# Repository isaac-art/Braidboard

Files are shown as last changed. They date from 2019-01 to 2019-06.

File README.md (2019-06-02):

## Braidboard
#### current version: 0119b

<hr>

This began as a sort of hardware version of [BriadLab](https://github.com/isaac-art/BraidLab) but is becoming some kind of distributed-cellular-pattern-generator.

<hr>

### Activity

- [02/06/19] Long break, but been thinking though making a simulator to get a better idea of how this all works. I need more memory in the boards, swapping between frame buffers doesnt allow enough room.
I'm going to sketchout some plans as to what the simulator will look like, but i think i will call it:

```
   ______      ___           __   ____                    __
  / __(_)_ _  / _ )_______ _(_)__/ / /  ___  ___ ________/ /
 _\ \/ /  ' \/ _  / __/ _ `/ / _  / _ \/ _ \/ _ `/ __/ _  / 
/___/_/_/_/_/____/_/  \_,_/_/\_,_/_.__/\___/\_,_/_/  \_,_/  

```

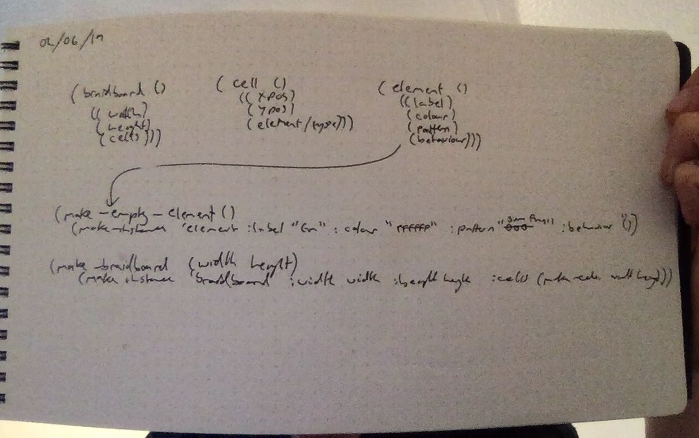
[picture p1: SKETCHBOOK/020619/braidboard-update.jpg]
classes


- [08/02/19] plan for the next week is to work on a font for drawing with. a set of tiles that can connect into different patterns.

- [08/02/19] playing around with images, thinking of having little pattern swatches for the screens, will need to make some bitmaps/font. they can then infect each other flipping bits of the weaves in each other? 

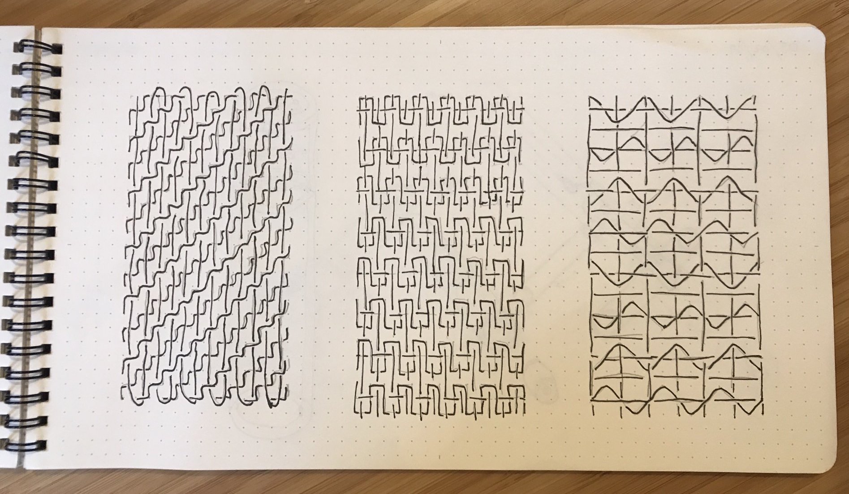
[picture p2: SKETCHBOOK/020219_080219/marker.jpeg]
drawings


<hr>

- [01/02/19] simple version running, 4 possible states, inherit from parents and pass to child. Next try drawing the knot crossings instead of numbers.

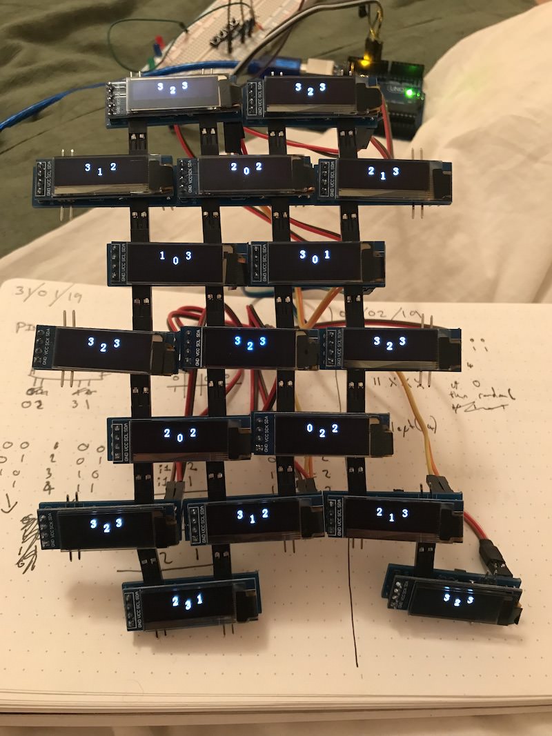
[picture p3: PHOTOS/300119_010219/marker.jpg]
first tests


<hr>

- [29/01/19] Aim to get some coding done this weekend 02/02/19.

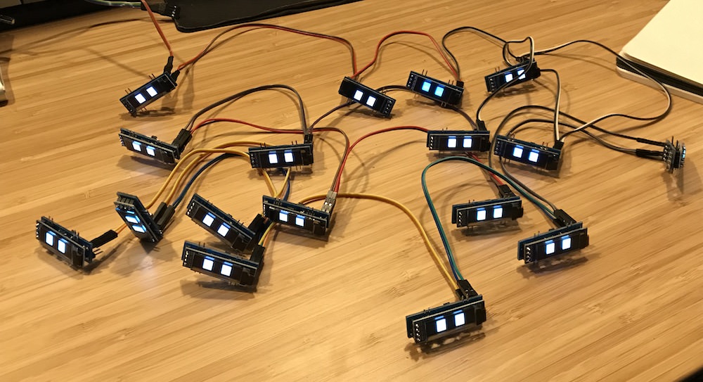
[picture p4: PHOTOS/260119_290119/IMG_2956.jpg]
assembled img


- [29/01/19] PCB has arrived! assembled 18 tiles

<hr>

- [26/01/19] PCB arrives on 29/01/19

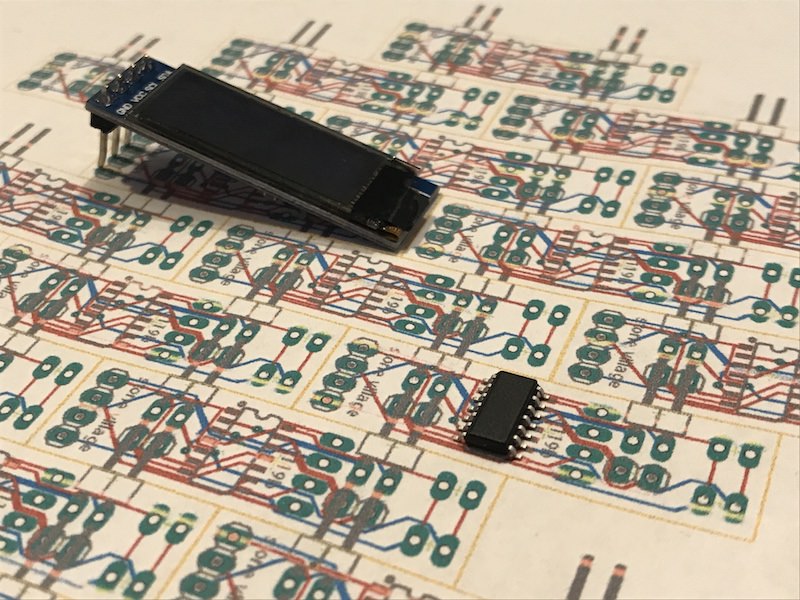
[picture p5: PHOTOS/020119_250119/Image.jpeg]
plan img


<hr>

### Requirements
* using the convenience of arduino, as i can use the arduino as isp to program the attinys
* for drawing to the screen i am using [datacute's Tiny4kOLED Library](https://github.com/datacute/Tiny4kOLED/) but i might strip it down some more if i end up needing to

<hr>

### Hardware
* pcb 0119b[front](https://github.com/isaac-art/Braidboard/blob/master/BOARD/0119b/braidboard_front.png) and back [back](https://github.com/isaac-art/Braidboard/blob/master/BOARD/0119b/braidboard_back.png)
* attiny84 (0119b using SOIC footprint) - [datasheet](http://ww1.microchip.com/downloads/en/DeviceDoc/8006S.pdf)
* OLED 128x32 I2C - the four pin type you find on [ebay](https://www.ebay.co.uk/itm/IIC-I2C-0-91-128x32-white-OLED-LCD-Display-Module-3-3v-5v-For-Arduino-PIC-HC/173751114146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)
* a bunch of breadboard spaced header pins & sockets
* power from a socket, or can use coin cells, i'm gonna try get it hooked to a solar panel
* i am avoiding making any enclosures at the moment

<hr>

### Specs
* attiny84 has 8k of space which should be plently for the first braid animation tests
* 3V-5V
* 12mm x 40 mm tiles - not sure how deep they are yet till i assemble one, should sit pretty flush but we'll see how they go

<hr>

### Futures
* bigger IC ?
* smaller IC !
* bigger/smaller screen ?
* colour ?
* add 20Mhz xtal ?

<hr>

### Pricing

| Item | ≈price | link |
|---|---|---|
| attiny84 soic | ≈£0.648 | [mouser](https://www.mouser.co.uk/_/?Keyword=attiny84&FS=True) |
| PCB: 12mm x 40mm 2 layer  lead-free | ≈£1.50 (@x10) | [pcbway](https://www.pcbway.com/project/shareproject/Braidboard_0119b.html) |
| 14 x male header 2.54 mm | ≈£0.70 | [amazon](https://www.amazon.co.uk/Pack-Single-2-54-Header-Connector/dp/B06XR8CV8P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) |
| Board Total | ≈£2.85 | 👍 |

<hr>

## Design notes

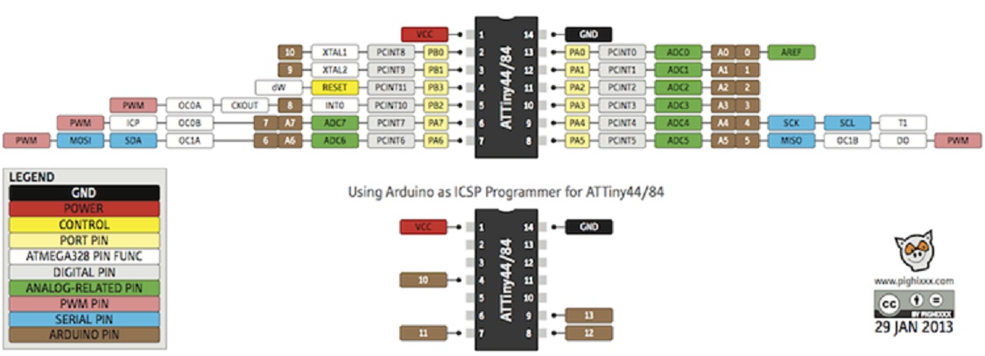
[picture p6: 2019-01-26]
RESEARCH/attiny84_attiny44_pinout_and_ISP_pins.jpg

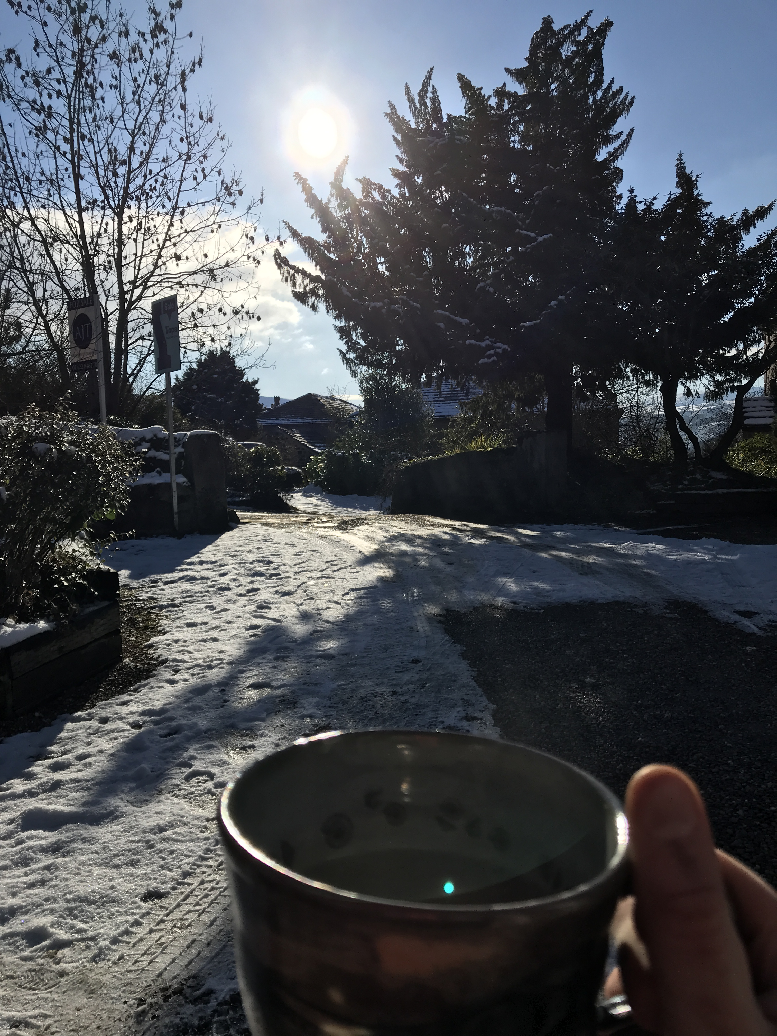
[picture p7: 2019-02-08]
PHOTOS/020219_080219/57080324673__812A1C96-25E1-43B2-873D-ADA10BF8E5E9.JPG

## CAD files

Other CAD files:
3D/0119b/braidboard_mockup.blend

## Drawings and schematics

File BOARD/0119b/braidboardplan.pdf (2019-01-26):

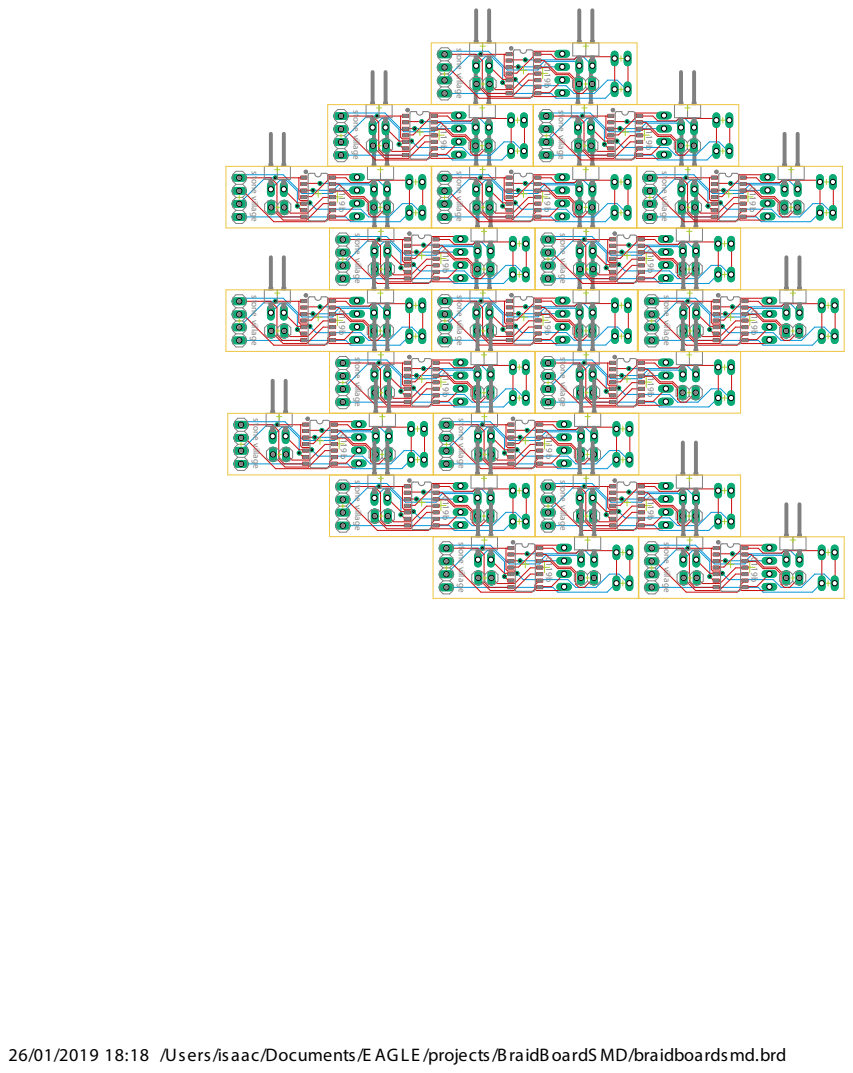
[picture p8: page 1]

26/01/2019 18:18 /Users/isaac/Documents/E AGLE /projects/BraidBoardS MD/braidboardsmd.brd

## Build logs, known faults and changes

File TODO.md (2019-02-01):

## TODO
<hr>

### General
* [x] on PCB 0119b arrived -> assemble
* [ ] create a font for the crossing types
* [ ] create bitmaps for the crossing types
* [ ] compare font & bitmap
* [ ] write the code to display the crossing on a tile
* [x] write the code to read input pins and change crossing in response
* [x] write the code to pass info to output pins
* [x] hook a few up see how they go

* [ ] DO SOMETHING INTERESTING WITH IT

<hr>

### Power
* [ ] what is the minimum power needed for n tiles
* [x] test with coin cells
* [ ] test with solar

<hr> 

### pcb revision
* [ ] magnetic connectors
* [ ] talk to neighbours to pass pixels?
* [ ] signal clarity checks
* [ ] board flexibility
* [x] how well do they tile
* [ ] mounting solutions? can i fit screw holes

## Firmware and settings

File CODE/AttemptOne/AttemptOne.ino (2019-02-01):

#include <Tiny4kOLED.h>

const int o1 = 10;
const int o2 = 9;
const int o3 = 8;
const int o4 = 7;
const int i1 = 0;
const int i2 = 1;
const int i3 = 2;
const int i4 = 3;

void setup() {
  pinMode(o1, OUTPUT);
  pinMode(o2, OUTPUT);
  pinMode(o3, OUTPUT);
  pinMode(o4, OUTPUT);
  pinMode(i1, INPUT);
  pinMode(i2, INPUT);
  pinMode(i3, INPUT);
  pinMode(i4, INPUT);
  
  digitalWrite(o1, LOW);
  digitalWrite(o2, LOW);
  digitalWrite(o3, LOW);
  digitalWrite(o4, LOW);
  
  oled.begin();
  oled.setFont(FONT8X16);
  oled.switchRenderFrame();
  initDisplay();
  updateState();
  oled.on();
}

void loop() {
  delay(50);
  updateState();
}

void updateState(){
  oled.setCursor(48, 1);
  if(digitalRead(i1) == LOW && digitalRead(i2) == LOW){
    oled.print(F("00"));
    digitalWrite(o1, HIGH);
    digitalWrite(o2, HIGH);
  }else if(digitalRead(i1) == LOW && digitalRead(i2) == HIGH){
    oled.print(F("01"));
    digitalWrite(o1, HIGH);
    digitalWrite(o2, LOW);
  }else if(digitalRead(i1) == HIGH && digitalRead(i2) == LOW){
    oled.print(F("10"));
    digitalWrite(o1, LOW);
    digitalWrite(o2, HIGH);
  }else if(digitalRead(i1) == HIGH && digitalRead(i2) == HIGH){
    oled.print(F("11"));
    digitalWrite(o1, LOW);
    digitalWrite(o2, LOW);
  }

  oled.setCursor(80, 1);
  if(digitalRead(i3) == LOW && digitalRead(i4) == LOW){
    oled.print(F("00"));
    digitalWrite(o3, HIGH);
    digitalWrite(o4, HIGH);
  }else if(digitalRead(i3) == LOW && digitalRead(i4) == HIGH){
    oled.print(F("01"));
    digitalWrite(o3, HIGH);
    digitalWrite(o4, LOW);
  }else if(digitalRead(i3) == HIGH && digitalRead(i4) == LOW){
    oled.print(F("10"));
    digitalWrite(o3, LOW);
    digitalWrite(o4, HIGH);
  }else if(digitalRead(i3) == HIGH && digitalRead(i4) == HIGH){
    oled.print(F("11"));
    digitalWrite(o3, LOW);
    digitalWrite(o4, LOW);
  }
  oled.switchFrame();
}

void initDisplay() {
//  oled.fill(0xFF);
  oled.clear();
  oled.switchFrame();
  oled.clear();
  oled.switchFrame();
}

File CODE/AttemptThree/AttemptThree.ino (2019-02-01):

#include <Tiny4kOLED.h>

const int out1 = 0;
const int out2 = 2;
const int out3 = 3;
const int out4 = 1;

const int in1 = 7;
const int in2 = 8;
const int in3 = 9;
const int in4 = 10;

int left = 0;
int right = 0;
int st = 0;

void setup() {
  pinMode(out1, OUTPUT);
  pinMode(out2, OUTPUT);
  pinMode(out3, OUTPUT);
  pinMode(out4, OUTPUT);
  pinMode(in1, INPUT_PULLUP);
  pinMode(in2, INPUT_PULLUP);
  pinMode(in3, INPUT_PULLUP);
  pinMode(in4, INPUT_PULLUP);
  digitalWrite(out1, LOW);
  digitalWrite(out2, LOW);
  digitalWrite(out3, LOW);
  digitalWrite(out4, LOW);

  
  oled.begin();
  oled.setFont(FONT8X16);
  oled.switchRenderFrame();
  initDisplay();
  updateState();
  oled.on();
}

void loop() {
  delay(1000);
  updateState();
}

void updateState(){
  oled.setCursor(40, 0);
  
  if(digitalRead(in1) == LOW && digitalRead(in2) == LOW){
    left = 0;
  }else if(digitalRead(in1) == LOW && digitalRead(in2) == HIGH){
    left = 1;
  }else if(digitalRead(in1) == HIGH && digitalRead(in2) == LOW){
    left = 2;
  }else if(digitalRead(in1) == HIGH && digitalRead(in2) == HIGH){
    left = round(random(0,3));
  }
  oled.print(left);

  oled.setCursor(80, 0);
  if(digitalRead(in3) == LOW && digitalRead(in4) == LOW){
    right = 0;
  }else if(digitalRead(in3) == LOW && digitalRead(in4) == HIGH){
    right = 1;
  }else if(digitalRead(in3) == HIGH && digitalRead(in4) == LOW){
    right = 2;
  }else if(digitalRead(in3) == HIGH && digitalRead(in4) == HIGH){
    right = round(random(0,3));
  }
  oled.print(right);

  oled.setCursor(60, 1);
  st = left + right;
  if(st == 4){
    st = 0;
  }else if(st == 5){
    st = 1;
  }else if(st == 6){
    st = 2;
  }
  oled.print(st);

  if(st == 0){
    digitalWrite(out1, HIGH);
    digitalWrite(out2, HIGH);
    digitalWrite(out3, HIGH);
    digitalWrite(out4, HIGH);
  }else if(st == 1){
    digitalWrite(out1, LOW);
    digitalWrite(out2, HIGH);
    digitalWrite(out3, LOW);
    digitalWrite(out4, HIGH);
  }else if(st == 2){
    digitalWrite(out1, HIGH);
    digitalWrite(out2, LOW);
    digitalWrite(out3, HIGH);
    digitalWrite(out4, LOW);
  }else {
    //3
    digitalWrite(out1, HIGH);
    digitalWrite(out2, HIGH);
    digitalWrite(out3, HIGH);
    digitalWrite(out4, HIGH);
  }
  
  oled.switchFrame();
}


void initDisplay() {
  oled.clear();
  oled.switchFrame();
  oled.clear();
  oled.switchFrame();
}

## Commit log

2019-01-26 add pcb links
2019-01-29 assembled 0119b
2019-01-30 add board 0119b order link
2019-06-02 adding SimBraidboard inits, also a link to tinyaudioboot so i remember
    SimBraidboard will be a simulator of this whole thing, that i should have made first really.
    TinyAudioBoot lets you flash attiny chips with audio over headphone slot, which raises a whole bunch of code sharing ideas and chips being able to flash their neighbours with updated scripts.
